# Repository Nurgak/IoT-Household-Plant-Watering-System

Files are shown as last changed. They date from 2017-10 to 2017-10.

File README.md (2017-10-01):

# IoT Household Plant Watering System

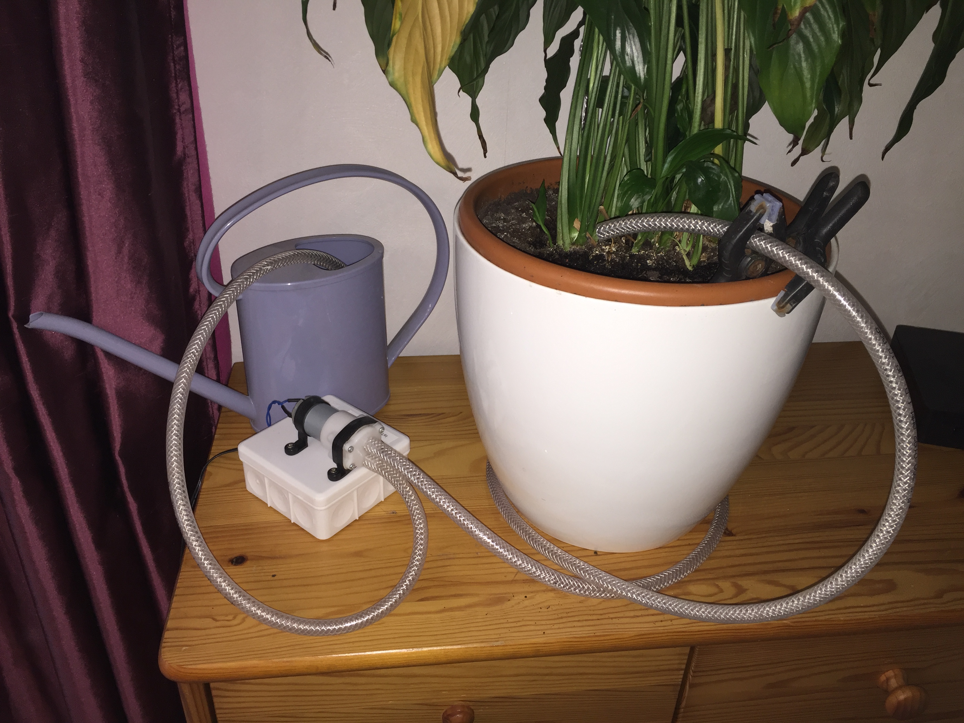
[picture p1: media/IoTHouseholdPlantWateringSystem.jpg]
IoT Household Plant Watering System


This project is about building an internet connected switch and use it together with a water pump to automatically irrigate household plants.

It is meant to be part of a larger home automation network, where nodes are controlled from a central hub via a [Node-RED](https://nodered.org/) server, it can also be used as stand-alone.

The [build process](https://hackaday.io/project/27108-iot-household-plant-watering-system) is documented on Hackaday.io.

## Hardware

The [complete bill-of-materials](https://hackaday.io/project/27108-iot-household-plant-watering-system) is documented on Hackaday.io. The electronic files, including schematic and layout, are under `/hardware`.

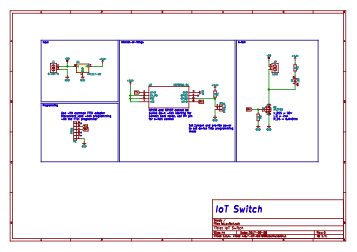
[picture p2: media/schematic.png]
Electronic schematic

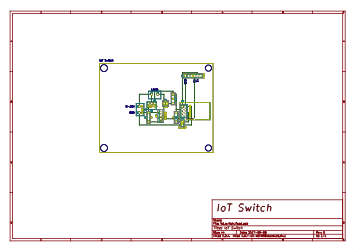
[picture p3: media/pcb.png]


The diaphragm pump is off of eBay and can function between 6-12V.

## Software

The software is developed with [Arduino IDE](https://www.arduino.cc/en/Main/Software) and the [ESP8266 core](https://github.com/esp8266/Arduino). The MQTT libraries are courtesy of [knolleary](https://github.com/knolleary/pubsubclient).

Before uploading the code the network credentials, MQTT broker address and port and the topic names need to be set. Once configured and uploaded the software can be [updated over WiFi](http://esp8266.github.io/Arduino/versions/2.0.0/doc/ota_updates/ota_updates.html) (Over-The-Air updating) from Arduino IDE.

## Usage

The system is controlled via [MQTT messages](https://en.wikipedia.org/wiki/MQTT), the suggested approach is to use [Node-RED](https://nodered.org/) server with an MQTT broker to configure the control flow.

The device subscribes to the following MQTT messages:

* **water**: sets the state of the pump, 1 activates and 0 deactivates it
* **timeout**: sets the maximum time the pump is allowed to function in milliseconds, if the pump is not stopped before the timeout runs out it will stop automatically
* **dutycycle**: sets the PWM duty cycle from 0 to 100% for the motor, allows to control the speed of the pump

The settings for the timeout and duty cycle are stored in the EEPROM and persist over reboots.

## License

The software is licensed under [GNU General Public License](https://en.wikipedia.org/wiki/GNU_General_Public_License).

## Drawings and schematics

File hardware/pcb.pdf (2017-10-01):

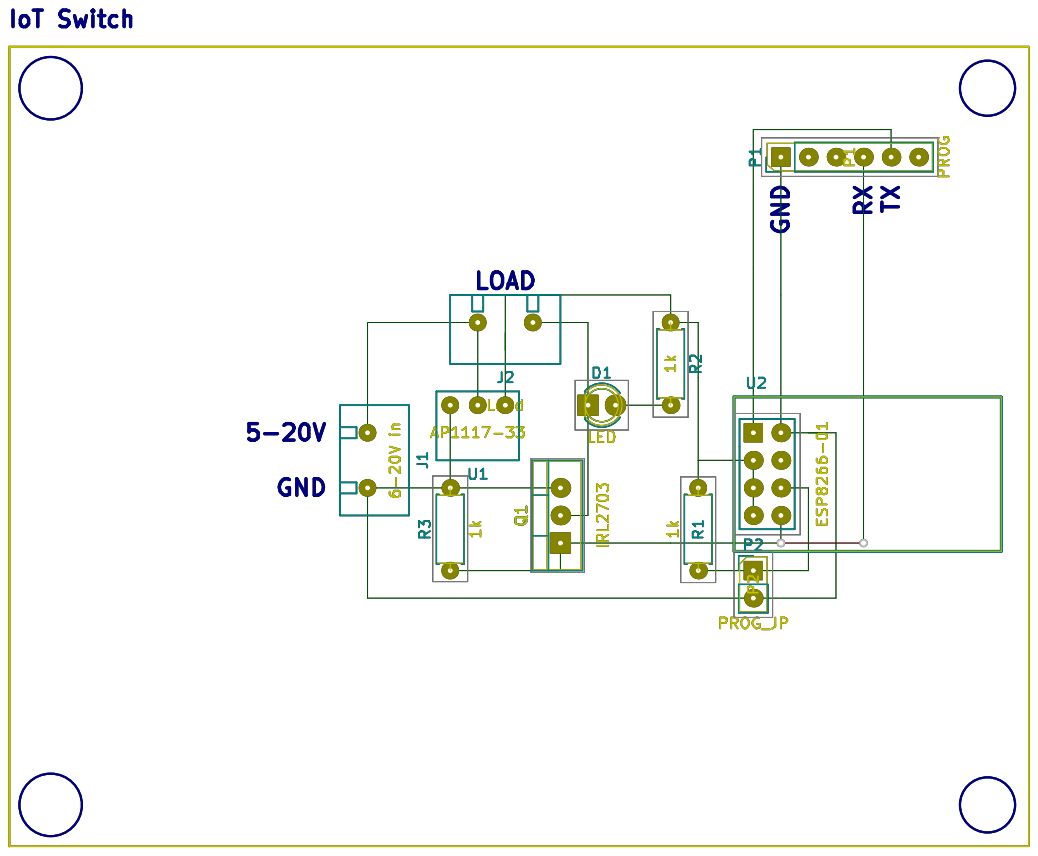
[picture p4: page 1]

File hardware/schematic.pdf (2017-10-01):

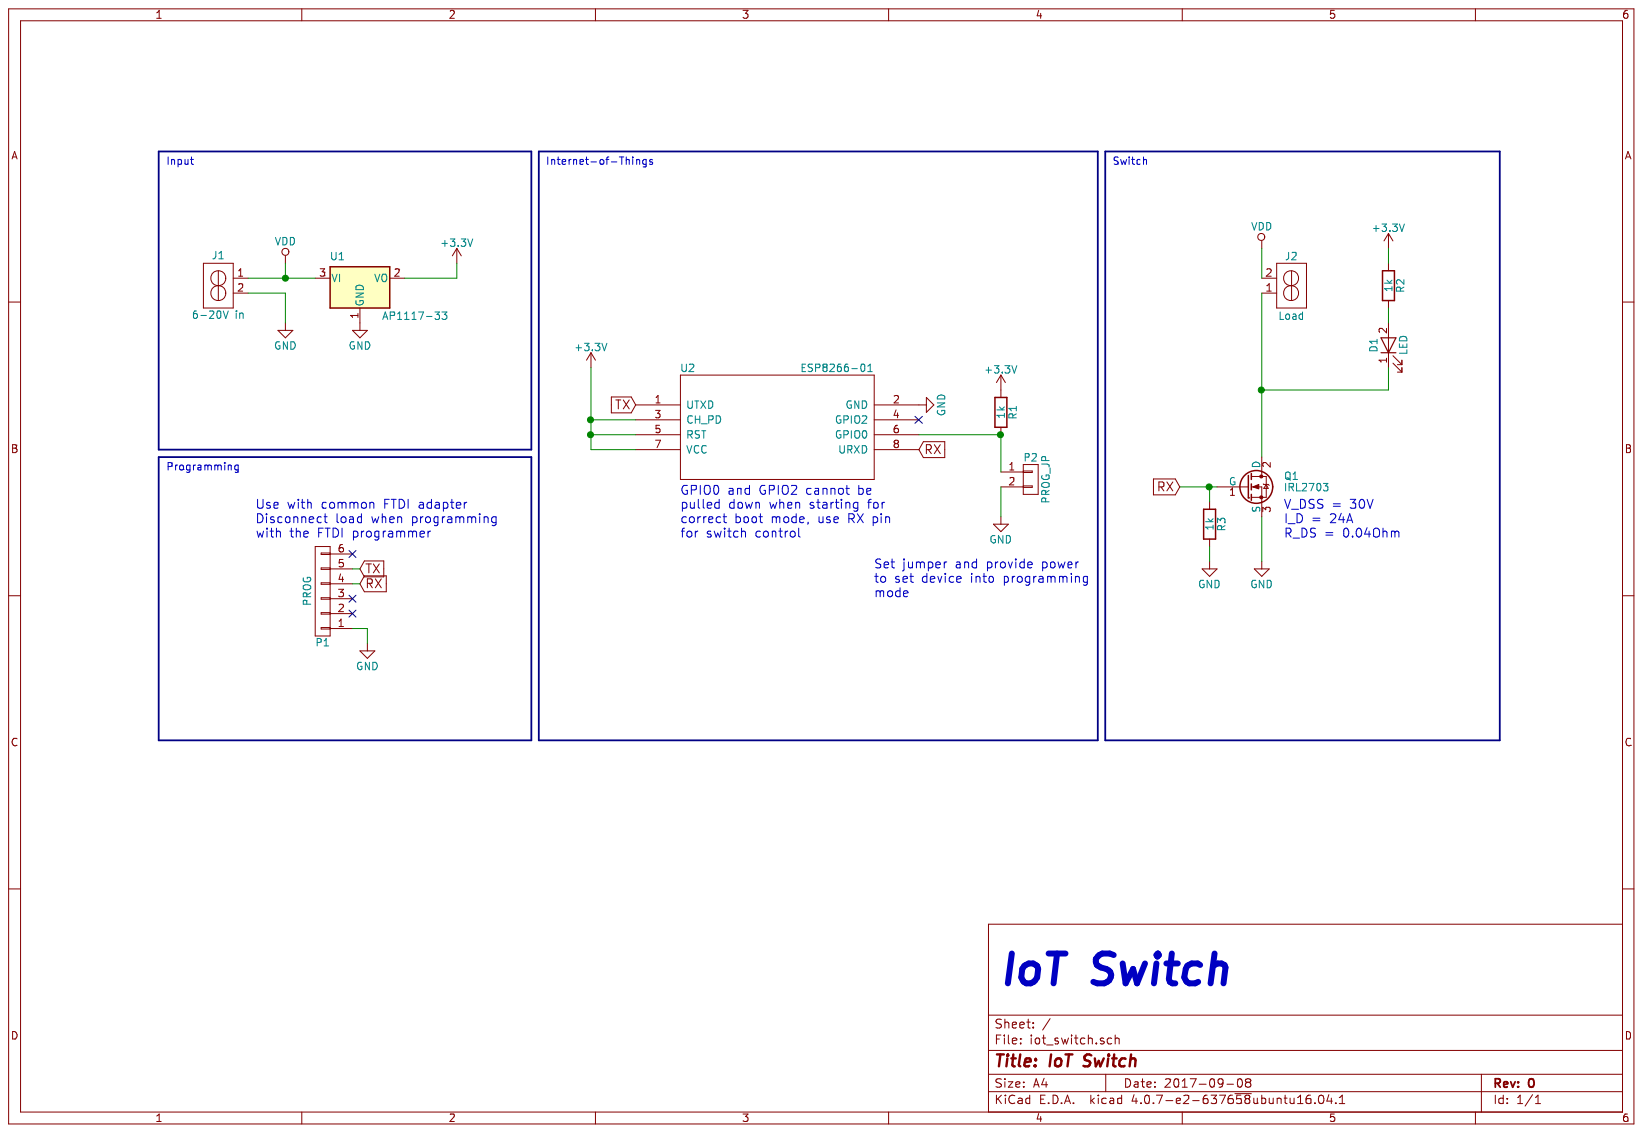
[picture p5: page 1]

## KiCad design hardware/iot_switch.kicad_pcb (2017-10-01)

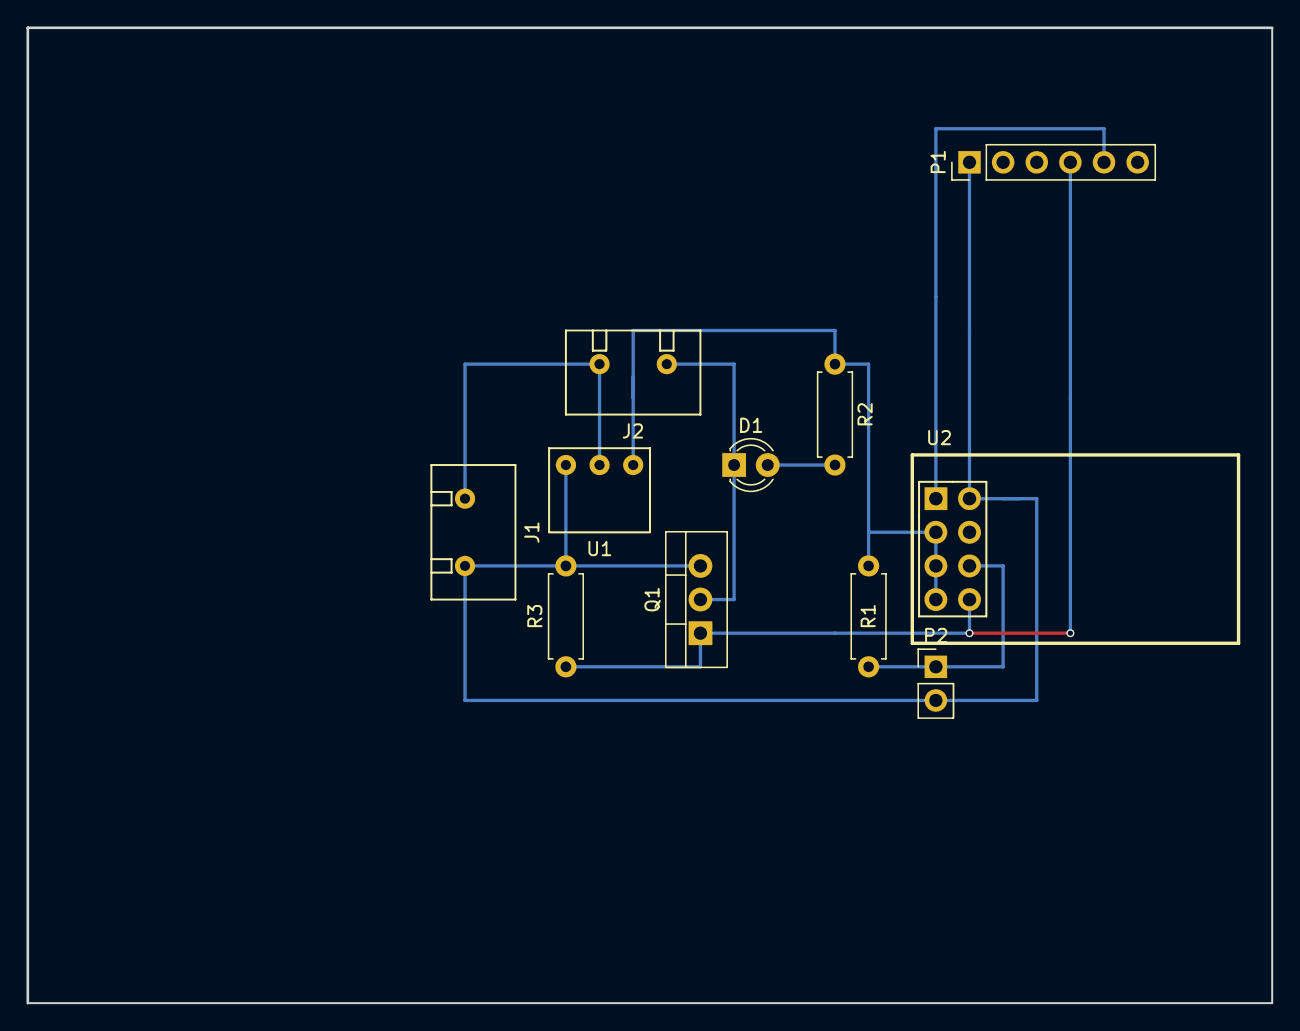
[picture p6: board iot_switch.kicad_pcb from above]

Board: 2 copper layers, 94.0 x 73.7 mm, 11 parts (0 on the bottom side), 8 nets.

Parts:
D1: LED; LED_D3.0mm
J1: 6-20V in; Screw_terminal
J2: Load; Screw_terminal
P1: PROG; Pin_Header_Straight_1x06_Pitch2.54mm
P2: PROG_JP; Pin_Header_Straight_1x02_Pitch2.54mm
Q1: IRL2703; TO-220_Vertical
R1, R2, R3: 1k; R_Axial_DIN0207_L6.3mm_D2.5mm_P7.62mm_Horizontal
U1: AP1117-33; 1117
U2: ESP8266-01; ESP-01

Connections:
+3V3: R1.1, R2.1, U1.2, U2.3, U2.5, U2.7
GND: J1.2, P1.1, P2.2, Q1.3, R3.2, U1.1, U2.2
unnamed: D1.1, J2.1, Q1.2
unnamed: D1.2, R2.2
unnamed: P2.1, R1.2, U2.6
RX: P1.4, Q1.1, R3.1, U2.8
TX: P1.5, U2.1
VDD: J1.1, J2.2, U1.3

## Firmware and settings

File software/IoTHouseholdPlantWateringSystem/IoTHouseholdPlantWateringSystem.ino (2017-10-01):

/*
  Software for the IoTHouseholdPlantWateringSystem based on the ESP8266
  Copyright (c) 2017 Karl Kangur. All rights reserved.
  This file is part of IoTHouseholdPlantWateringSystem.
  IoTHouseholdPlantWateringSystem is free software: you can redistribute it and/or modify
  it under the terms of the GNU General Public License as published by
  the Free Software Foundation, either version 3 of the License, or
  (at your option) any later version.
  IoTHouseholdPlantWateringSystem is distributed in the hope that it will be useful,
  but WITHOUT ANY WARRANTY; without even the implied warranty of
  MERCHANTABILITY or FITNESS FOR A PARTICULAR PURPOSE.  See the
  GNU General Public License for more details.
  You should have received a copy of the GNU General Public License
  along with IoTHouseholdPlantWateringSystem.  If not, see <http://www.gnu.org/licenses/>.
*/

/*
 * File:    IoTHouseholdPlantWateringSystem.ino
 * Author:  Karl Kangur <karl.kangur@gmail.com>
 * Licnece: GPL
 * URL:     https://github.com/Nurgak/IoT-Household-Plant-Watering-System
 */

#include <ESP8266WiFi.h>
#include <PubSubClient.h>
#include <ArduinoOTA.h>
#include <EEPROM.h>

#define SWITCH_PIN 3
#define WIFI_RECONNECT_DELAY_MS 500
#define DUTYCYCLE_MIN 0
#define DUTYCYCLE_MAX 100
// Used EEPROM bytes must be a multiple of 4
#define EEPROM_USED_MEMORY_BYTES 4
#define EEPROM_ADDR_DUTYCYCLE 0
#define EEPROM_ADDR_DURATION 1

const char * ssid = "...";
const char * password = "...";
const char * host_name = "IoTHouseholdPlantWateringSystem";
const char * mqtt_server = "192.168.0.1";
const unsigned int mqtt_port = 1883;

// Define the names for the topics
const char * topic_water = "water";
const char * topic_dutycycle = "dutycycle";
const char * topic_timeout = "timeout";

WiFiClient espClient;
PubSubClient client(espClient);

byte dutyCycle;
unsigned int duration;
long timeout;

void setup()
{
  // Set LED and switch pins to outputs
  pinMode(BUILTIN_LED, OUTPUT);
  pinMode(SWITCH_PIN, OUTPUT);

  // Connect to access point and MQTT broker
  setup_wifi();
  client.setServer(mqtt_server, mqtt_port);
  client.setCallback(callback);

  // Stop the motor when updating
  ArduinoOTA.onStart([]()
  {
    stop();
  });

  // Show update progress on the built-in LED by toggling it
  ArduinoOTA.onProgress([](unsigned int progress, unsigned int total)
  {
    digitalWrite(BUILTIN_LED, !digitalRead(BUILTIN_LED));
  });

  // Turn LED off (HIGH state) when completed
  ArduinoOTA.onEnd([]()
  {
    digitalWrite(BUILTIN_LED, HIGH);
  });

  // Configure over-the-air update
  ArduinoOTA.setHostname(host_name);
  ArduinoOTA.begin();

  // Indicate the number of bytes being used in the EEPROM
  EEPROM.begin(EEPROM_USED_MEMORY_BYTES);
  // Load the configuration from EEPROM
  dutyCycle = loadIntEEPROM<byte>(EEPROM_ADDR_DUTYCYCLE);
  duration = loadIntEEPROM<unsigned int>(EEPROM_ADDR_DURATION);

  // Set duty cycle from 0 to 100 instead of the default 0-1023
  analogWriteRange(DUTYCYCLE_MAX);
}

void setup_wifi()
{
  WiFi.begin(ssid, password);
  while(WiFi.status() != WL_CONNECTED)
  {
    // Blink LED fast while connecting
    digitalWrite(BUILTIN_LED, !digitalRead(BUILTIN_LED));
    delay(250);
  }

  // LED will stay lit after connection
  digitalWrite(BUILTIN_LED, LOW);
}

template<typename T> void saveIntEEPROM(unsigned int address, T value)
{
  for(size_t i = 0; i < sizeof(value); ++i)
  {
    // Write the ith byte to EEPROM
    EEPROM.write(address + i, (value >> (8 * i)) & 0xff);
  }
  EEPROM.commit();
}

template<typename T> T loadIntEEPROM(unsigned int address)
{
  // Initialise return value
  T value = 0;
  for(size_t i = 0; i < sizeof(value); ++i)
  {
    // Read the ith byte from EEPROM to value
    value |= EEPROM.read(address + i) << (8 * i);
  }
  return value;
}

// MQTT callback for all topics
void callback(char* topic, byte* payload, unsigned int length)
{
  // Make sure there is space in the buffer for a terminator character
  if(length >= MQTT_MAX_PACKET_SIZE)
  {
    return;
  }
  // Add a termintor so String() would work properly
  payload[length] = '\0';
  String data = String((char*)payload);
  // Transform payload to an integer
  int temp = data.toInt();
  
  if(strcmp(topic, topic_water) == 0)
  {
    if(temp == 0)
    {
      stop();
    }
    else if(temp == 1 && duration > 0)
    {
      // Turn on the switch
      timeout = millis() + duration;
      analogWrite(SWITCH_PIN, dutyCycle);
    }
  }
  else if(strcmp(topic, topic_dutycycle) == 0)
  {
    // Sanitize data
    if(temp < DUTYCYCLE_MIN)
    {
      temp = DUTYCYCLE_MIN;
    }
    else if(temp > DUTYCYCLE_MAX)
    {
      temp = DUTYCYCLE_MAX;
    }
    dutyCycle = temp;
    // Save configuration to EEPROM
    saveIntEEPROM(EEPROM_ADDR_DUTYCYCLE, dutyCycle);
  }
  else if(strcmp(topic, topic_timeout) == 0)
  {
    // Sanitize data
    duration = temp < 0 ? 0 : temp;
    // Save configuration to EEPROM
    saveIntEEPROM(EEPROM_ADDR_DURATION, duration);
  }

  // Acknowledge message by blinking the built-in LED
  digitalWrite(BUILTIN_LED, !digitalRead(BUILTIN_LED));
}

void stop()
{
  timeout = 0;
  // Must write 0 to cancel the PWM
  analogWrite(SWITCH_PIN, 0);
  // Make sure the switch is off
  digitalWrite(SWITCH_PIN, LOW);
}

void reconnect()
{
  while(!client.connected())
  {
    if(client.connect(host_name))
    {
      // Subscribe to 
      client.subscribe(topic_water);
      client.subscribe(topic_dutycycle);
      client.subscribe(topic_timeout);
    }
    else
    {
      delay(WIFI_RECONNECT_DELAY_MS);
    }
  }
}

void loop()
{
  if(!client.connected())
  {
    reconnect();
  }
  client.loop();

  // Turn off the switch when the timeout is reached, rollover-safe
  if(timeout && duration && (long)(millis() - timeout) >= 0)
  {
    stop();
  }

  // Check if a program update is coming
  ArduinoOTA.handle();
}
